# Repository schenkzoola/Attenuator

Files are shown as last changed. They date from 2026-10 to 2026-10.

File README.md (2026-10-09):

<picture>
  <source media="(prefers-color-scheme: dark)" srcset="docs/images/logo-light.png">
  Schenktronics
</picture>

# Levels

A 3HP Eurorack dual passive attenuator from **Schenktronics**. It has two channels, each with an input, an output and a level knob. The second input is normalled to the first, so one signal can be sent out at two different levels. It needs no power.

Levels front panel

## Features

- 3HP Eurorack, 15 mm deep, and it needs no power
- Two channels, each turning a signal down from full level to off
- In 2 is normalled to In 1: one input, two outputs at independent levels
- Works on audio, CV, gates and bipolar signals
- The whole kit is through-hole, with 22 solder joints

## Documentation

| Document | For | PDF |
|---|-----|-----|
| [User Manual](docs/manual.md) | Using the module | [PDF](docs/pdf/levels-manual.pdf) |
| [Assembly Guide](docs/assembly-guide.md) | Building the kit | [PDF](docs/pdf/levels-assembly-guide.pdf) |
| [Bill of Materials](docs/BOM.md) ([CSV](docs/BOM.csv)) | Parts and sourcing | |

## Repository layout

```
hardware/
  levels/                      Main PCB (KiCad 5.1 schematic, KiCad 10 PCB)
    Levels.sch                   Schematic
    Levels.kicad_pcb             PCB layout
    Levels.step                  3D model
    BOM.ods                      Original BOM spreadsheet
  panel/                       Faceplate (KiCad 10, made as an aluminium PCB)
    LevelsFaceplate.kicad_pcb    Faceplate layout
manufacturing/
  levels/                      Gerbers and drill files for the main PCB
  panel/                       Gerbers, drill files and the panel drawing (.dxf)
docs/                         Manual, assembly guide, BOM, images
  drawings/                     Scripts that generate the drawings
  pdf/                          PDF versions and their build settings
```

## Fabrication

| Board | Size | Layers | Thickness | Notes |
|---|---|---|---|---|
| Main PCB | 15 × 100 mm | 2 | 1.6 mm | Standard green is fine |
| Faceplate | 15 × 128.5 mm | 1 | 1.6 mm | Aluminium PCB, white solder mask, black silkscreen. Only the front copper layer is used, so FR4 works too. |

Upload the matching `*Gerbers.zip` to any common PCB fab.

## License

This hardware design and its documentation are licensed under [CC BY-NC-SA 4.0](https://creativecommons.org/licenses/by-nc-sa/4.0/). See [LICENSE](LICENSE).

The Schenktronics name and logo are trademarks of Nathan Schenk and are not covered by the CC BY-NC-SA 4.0 license.

## Links

- Tindie: <https://www.tindie.com/products/schenktronics/passive-attenuator/>
- ModularGrid: <https://modulargrid.net/e/schenktronics-atten>
- Build video: <https://www.youtube.com/watch?v=RKkGsIigaSM>
- Website: <https://schenktronics.com>

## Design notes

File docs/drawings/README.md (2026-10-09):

# Drawings

The drawings in the docs are generated by three scripts in this repo, plus one that lives elsewhere (see "Outline drawings" below). The three here use only the Python standard library.

| Script | Makes | From |
|---|---|---|
| [`make_panel_svg.py`](make_panel_svg.py) | `panel.svg`, used in the manual, and `panel-plain.svg`, the panel without captions, used on packaging labels | The faceplate KiCad file |
| [`make_assembly_svgs.py`](make_assembly_svgs.py) | `assembly-*.svg`, used in the assembly guide | The main PCB KiCad file |
| [`make_patch_svgs.py`](make_patch_svgs.py) | `patch-*.svg`, the patch examples in the manual | The faceplate KiCad file |

## Panel drawing

The panel drawing in the [user manual](../manual.md) ([`../images/panel.svg`](../images/panel.svg)) is generated from the KiCad faceplate file, [`LevelsFaceplate.kicad_pcb`](../../hardware/panel/LevelsFaceplate.kicad_pcb).

After changing the faceplate in KiCad, run this from anywhere in the repo:

```sh
python3 docs/drawings/make_panel_svg.py
```

### What it reads

| From the KiCad file | Used for |
|---|---|
| `Edge.Cuts` lines | Panel outline |
| Mounting-hole footprints and their drill sizes | Jacks (Ø6.0), the knobs (Ø7.0) and the rack screw holes |
| `F.SilkS` lines and text | The divider line and the labels |
| `F.SilkS` circles | The rings around the jacks: a thin ring marks an input, a bold ring an output |
| The `SchentronicsLogo` footprint | The logo, read as its silkscreen polygons and placed at the footprint's position and rotation |

The script tells holes apart by drill size, so if you change a hole size, update `JACK` and `POT` at the top of the script. The knobs are drawn by the script, and the "Level", "In" and "Out" captions are added by the script, not read from KiCad.

The faceplate file is KiCad 10's S-expression format, read with a small generic S-expression parser in the script (not regexes), since the logo's artwork lives inside a footprint and needs that footprint's position and rotation applied to come out right.

## Assembly drawings

After changing the main PCB in KiCad, run:

```sh
python3 docs/drawings/make_assembly_svgs.py
```

| Drawing | How it's made |
|---|---|
| `assembly-1-parts.svg` | Front board view, drawn from the board outline, pads and front silkscreen in the PCB file |
| `assembly-2-faceplate.svg` | Side diagram. The part positions along the board come from the PCB file, and the heights are approximate. |
| `assembly-3-solder.svg` | Back board view, drawn from the PCB file |

Like the panel script, it reads `Levels.kicad_pcb` with the same generic S-expression parser (imported from `make_panel_svg.py`), not regexes — the main PCB file is KiCad 10 format too. It only keeps footprints whose reference starts with `RV` or `J`, so non-component footprints (e.g. the Schenktronics logo artwork on the back silkscreen) don't get drawn as if they were parts.

The side view assumes the faceplate sits 12.5 mm further up than the PCB, matching the two KiCad files. If you move the parts on either board, update `OFFSET` near the top of the figures section.

## Patch examples

The patch drawings reuse the panel drawing and add module boxes and cables. Each example is a short function in the script, for example:

```python
def tame(data):
    p = Patch(data)
    p.source("In 1", "LFO", "out")
    p.dest("Out 1", "Filter", "cutoff CV in")
    p.note("Level 1", "Level 1", "sets the depth")
    ...
```

Jacks are named as on the panel: `In 1`, `Out 1`, `In 2` and `Out 2`. Sources go on the left, destinations on the right. `note()` puts a caption beside a knob or jack. Pass `color=BLUE` to draw a second signal. To add an example, write a new function, add it to the list in `main()`, and run:

```sh
python3 docs/drawings/make_patch_svgs.py
```

## Outline drawings

`outline-front.svg`, `outline-side.svg`, one `outline-iso-{top,bottom}-{left,right}.svg` per corner, and `outline-bare-parts.svg` (the panel and bare PCB side by side, for the assembly guide's "before you start" shot) are real projections straight from [`ST-02_Levels.step`](../../hardware/ST-02_Levels.step) in `hardware/` — not diagrams. They replace the old product photos in the README, manual and assembly guide. All four isometric corners are generated every run so there's always a fresh set to pick a hero shot from; `outline-iso-top-left.svg` is the one currently used.

**The generator for these doesn't live in this repo.** Unlike the three scripts above, it needs no product-specific logic — point it at any product's STEP files and it works unchanged — so it's kept as one shared tool in the private `schenktronics-business` repo (`claude/skills/schenktronics-product-docs/assets/drawings/make_outline_svg.py`) rather than forked into every product. Regenerate from this repo's root:

```sh
pip install cadquery  # no FreeCAD or other CAD tooling needed
python3 ~/Products/schenktronics-business/claude/skills/schenktronics-product-docs/assets/drawings/make_outline_svg.py \
  --assembly hardware/ST-02_Levels.step \
  --panel hardware/panel/LevelsFaceplate.step \
  --board hardware/levels/Levels.step \
  --out docs/images \
  --product "Levels"
```

(or add a view name at the end, e.g. `... outline-front.svg`, to regenerate just that one)

**This is slow, and not predictably so — read the module docstring in that script before touching it.** Short version: a straight-on view down an axis where many cylindrical parts line up end-on (every jack here, viewed from the front) is a degenerate case for exact-BRep HLR, both slow and prone to rendering a different jack inconsistently on every attempt. The fix that worked — a perspective projection with its apex centered on the model, not tilting the orthographic direction — is explained in full in the script itself. That script is the one copy serving every product, so fixes and lessons belong there, not duplicated into each product repo's own docs. One Levels-specific lesson that *did* belong in the shared script: `outline-bare-parts.svg` initially failed here (`Bnd_Box is void`) because a pot's body overhangs the bare board's edge, which the script's board-matching tolerance was too tight to handle — fixed 2026-10-08 by widening that tolerance (see `find_board_solids` in the script).

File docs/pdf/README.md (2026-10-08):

# PDFs

Printable versions of the docs:

- [User Manual (PDF)](levels-manual.pdf)
- [Assembly Guide (PDF)](levels-assembly-guide.pdf)

These are built from [`../manual.md`](../manual.md) and [`../assembly-guide.md`](../assembly-guide.md). **Don't edit the PDFs by hand.** Edit the Markdown instead.

The build tool lives in [schenktronics-docs-tools](https://github.com/schenkzoola/schenktronics-docs-tools), so this repo only holds its settings, in [`config.json`](config.json): the product name, PCB version and which documents to build.

## Automatic builds

The [Build PDFs workflow](../../.github/workflows/pdf.yml) rebuilds the PDFs whenever the docs, their images or `config.json` change on `master`, and commits the new PDFs back. After you push a docs change, wait a minute and then `git pull` to get the rebuilt PDFs.

After an update to schenktronics-docs-tools, run the workflow by hand from the repo's **Actions** tab to rebuild with the new version.

## Previewing locally

See [Previewing locally](https://github.com/schenkzoola/schenktronics-docs-tools#previewing-locally) in the tools repo. In short:

```sh
node ~/Products/schenktronics-docs-tools/pdf/build.mjs docs/pdf/config.json
```

Don't commit the PDFs this produces. Let the workflow build the committed copies.

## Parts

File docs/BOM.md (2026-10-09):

# Bill of Materials — Levels v1.0

A machine-readable copy is in [BOM.csv](BOM.csv). The original spreadsheet is [hardware/levels/BOM.ods](../hardware/levels/BOM.ods).

| Qty | Reference | Part | Manufacturer / Part No. | Notes |
|----:|---|---|---|---|
| 4 | J1–J4 | 3.5 mm mono switched jack, vertical PCB mount, with nut | QingPu WQP-PJ398SM or WQP518MA, or equivalent. Either one works. | [Datasheet / product page](http://www.qingpu-electronics.com/en/products/WQP-PJ398SM-362.html). The switched (normalling) contact is used on J3 (In 2) only, so J3 must be a switched jack. |
| 2 | RV1, RV2 | Potentiometer, 100 kΩ linear, 9 mm, vertical PCB mount with board-lock lugs, 6 mm D shaft (20 mm long), bushingless | Bourns PTV09A-4020F-B104, or equivalent | [Mouser product page](https://www.mouser.com/en/ProductDetail/Bourns/PTV09A-4020F-B104?qs=Qzws7J6gxqwTQanrz88HwA%3D%3D), [datasheet (PTV09 series)](https://www.bourns.com/docs/Product-Datasheets/PTV09.pdf). No center detent. No threaded bushing or nut — held by the PCB's two mounting lugs (the same mounting style as the Attenuverter's pot). An equivalent must fit the 9 mm footprint (3 pins in a row, 2 mounting lugs) and have a 6 mm shaft that fits the knob. |
| 2 | — | Knob, 12 mm | Davies Molding 1221-J, or equivalent | [Mouser 5164-1221-J](https://www.mouser.com/en/ProductDetail/Davies-Molding/1221-J?qs=AaRlLUpeMsymqGRd5ndiLA%3D%3D). Pushes directly onto the pot's shaft — the pot has no nut, so this knob has no skirt (unlike the earlier 1227-J). An equivalent must fit the pot shaft. |
| 1 | — | Main PCB, 15 × 100 mm, 2-layer, 1.6 mm FR4 | Schenktronics | Gerbers: [LevelsGerbers.zip](../manufacturing/levels/LevelsGerbers.zip) |
| 1 | — | Faceplate, 3HP (15 × 128.5 mm), 1.6 mm aluminium PCB | Schenktronics | Single-sided, so it can also be made in FR4. Gerbers: [LevelsFaceplateGerbers.zip](../manufacturing/panel/LevelsFaceplateGerbers.zip) |

## Not included

| Qty | Part | Notes |
|----:|---|---|
| 2 | M3 rack screws | Supplied with most Eurorack cases. |

No power cable is needed. The module is passive.

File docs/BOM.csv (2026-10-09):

Qty | Reference | Description | Manufacturer | Part Number | Link
4 | J1-J4 | 3.5mm mono switched jack, vertical, with nut (J3 must be switched) | QingPu | WQP-PJ398SM or WQP518MA | http://www.qingpu-electronics.com/en/products/WQP-PJ398SM-362.html
2 | RV1, RV2 | Potentiometer, 100k linear, 9mm, vertical PCB mount with board-lock lugs, 6mm D shaft (20mm long), bushingless, no nut (or equivalent) | Bourns | PTV09A-4020F-B104 | https://www.mouser.com/en/ProductDetail/Bourns/PTV09A-4020F-B104
2 |  | Knob, 12mm, fits pot shaft directly, not skirted (or equivalent) | Davies Molding | 1221-J | https://www.mouser.com/en/ProductDetail/Davies-Molding/1221-J
1 |  | Main PCB, 15x100mm, 2-layer, 1.6mm | Schenktronics | Levels v1.0
1 |  | Faceplate, 3HP, 1.6mm aluminium PCB | Schenktronics | Levels Faceplate

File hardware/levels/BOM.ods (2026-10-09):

Qty | Part No | Manufacturer | Description | Link
4 | WQP-WQP518MA | QuingPu | 3.5mm Jack with nut | http://www.qingpu-electronics.com/en/products/WQP-PJ398SM-362.html
2 | PTV09A-4020F-B104 | Bourns | POT 100K OHM 1/20W PLASTIC LIN | https://www.mouser.com/en/ProductDetail/Bourns/PTV09A-4020F-B104?qs=Qzws7J6gxqwTQanrz88HwA%3D%3D
2 | 1221-J | Davies Molding | 15mm x 22mm skirted knob | https://www.mouser.com/en/ProductDetail/Davies-Molding/1221-J?qs=AaRlLUpeMsymqGRd5ndiLA%3D%3D
1 | PCB | Schenktronics
1 | Faceplate | Schenktronics

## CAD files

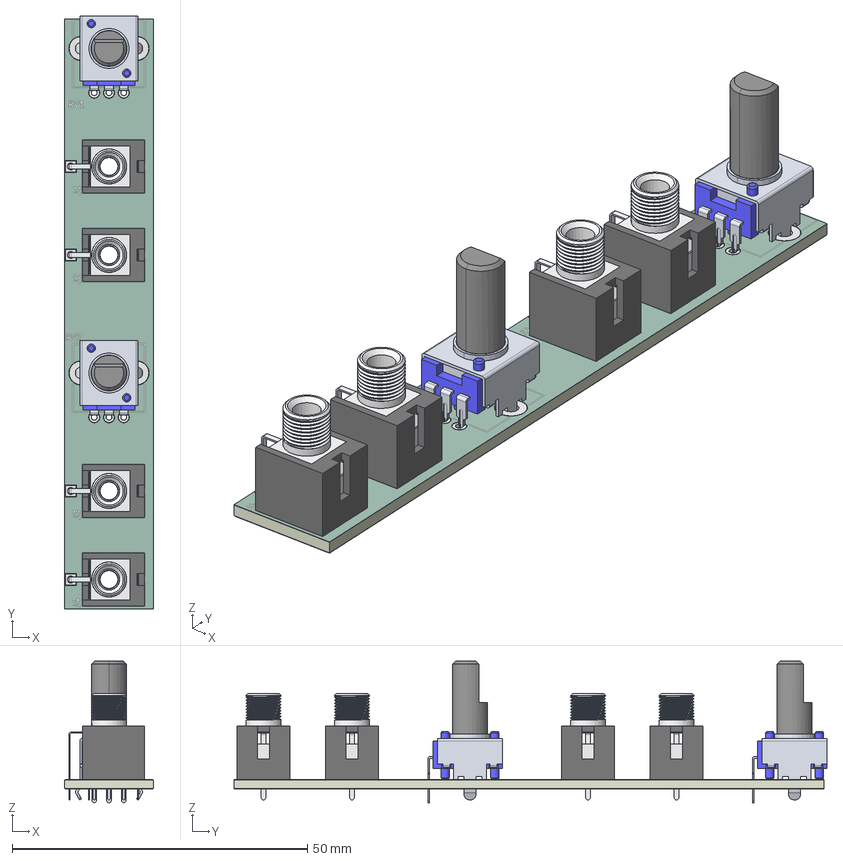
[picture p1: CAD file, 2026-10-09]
hardware/levels/Levels.step
15.0 x 100.5 x 24.0 mm
Thonkiconn - PJ398SM v10 x 4
PTV09A-4X20F-XXXCX_2 x 2
PTV09A-4X20F-XXXCX x 2
Levels_copper
Levels_pad
Levels_silkscreen x 2
Levels_soldermask x 2
Levels_PCB

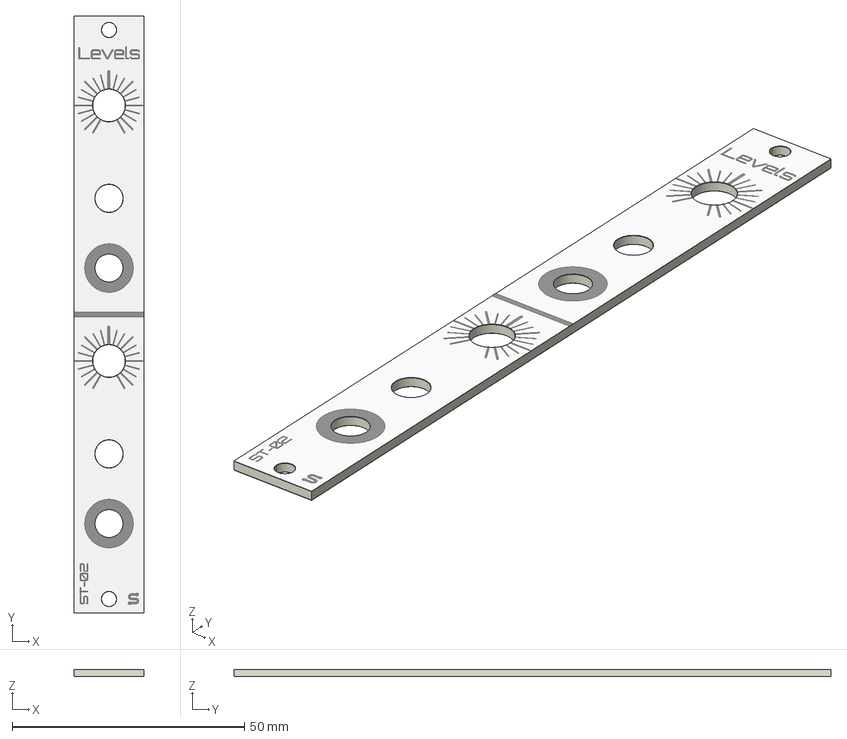
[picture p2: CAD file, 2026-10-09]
hardware/panel/LevelsFaceplate.step
15.0 x 128.5 x 1.64 mm
LevelsFaceplate-unsaved-export-oxjU8a_copper
LevelsFaceplate-unsaved-export-oxjU8a_silkscreen
LevelsFaceplate-unsaved-export-oxjU8a_soldermask x 2
LevelsFaceplate-unsaved-export-oxjU8a_PCB

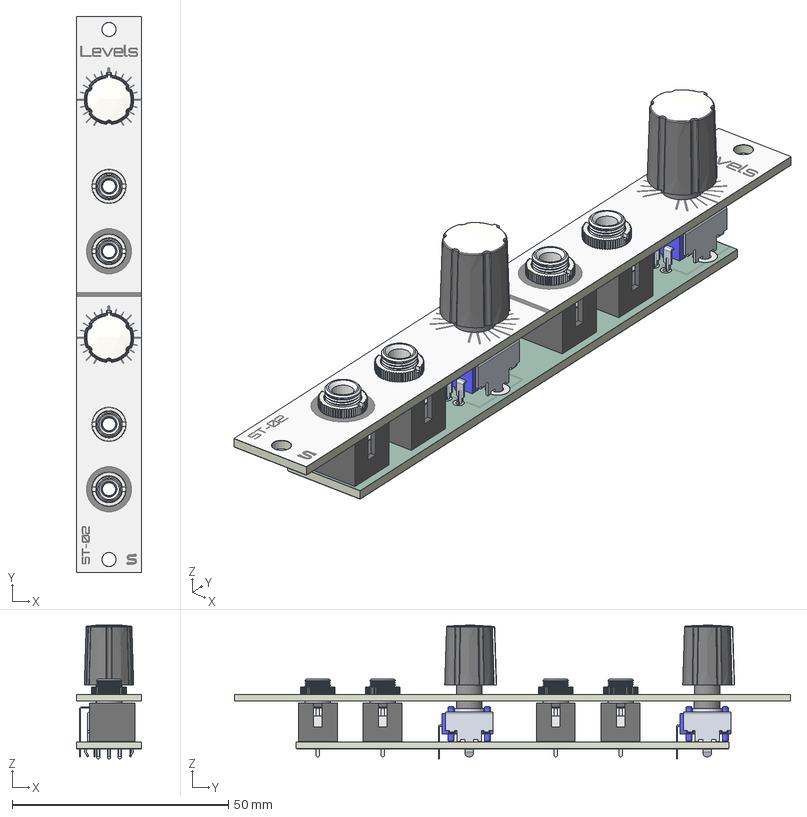
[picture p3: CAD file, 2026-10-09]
hardware/ST-02_Levels.step
15.0 x 128.5 x 31.0 mm
Thonkiconn - PJ398SM v10 x 4
PTV09A-4X20F-XXXCX_2 x 2
PTV09A-4X20F-XXXCX x 2
Levels_copper
Levels_pad
Levels_silkscreen
Levels_silkscreen_1
Levels_soldermask
Levels_soldermask_1
Levels_PCB
LevelsFaceplate-unsaved-export-oxjU8a_copper
LevelsFaceplate-unsaved-export-oxjU8a_silkscreen
LevelsFaceplate-unsaved-export-oxjU8a_soldermask
LevelsFaceplate-unsaved-export-oxjU8a_soldermask_1
LevelsFaceplate-unsaved-export-oxjU8a_PCB
Davies 1221-J x 2

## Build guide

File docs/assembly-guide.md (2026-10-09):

# Levels — Assembly Guide

Building this kit takes about 20–30 minutes and needs 22 solder joints. It is a good first Eurorack kit.

**Prefer to watch?** There's a video of the whole build: [Watch me solder together a passive attenuator module!](https://www.youtube.com/watch?v=RKkGsIigaSM)

The faceplate and the bare PCB, before assembly

## What you need

### Kit contents

Check your kit against this list before you start (full details in the [BOM](BOM.md)):

- [ ] 1 × main PCB
- [ ] 1 × faceplate
- [ ] 4 × 3.5 mm jacks with nuts
- [ ] 2 × 100 kΩ linear potentiometers
- [ ] 2 × knobs

### Tools

- Soldering iron (about 330–360 °C for leaded solder)
- Solder
- Flush cutters
- Multimeter with continuity (beep) and resistance modes
- Nut driver or wrench for the jack nuts (optional, but it avoids scratching the panel)

## Before you start

- The pots and jacks go on the **front** of the PCB, which is the side with the part outlines (RV1, RV2, J1–J4). The side printed "ST-02 v1.0 / Levels / schenktronics.com" is the back, and you solder there.
- **Do not solder anything until the faceplate is fitted.** The pot shafts and jacks all pass through the faceplate, which holds them in line while you solder. Parts soldered first can end up crooked in their panel holes.

## Step 1 — Fit the pots and jacks

1. Push the two pots into RV1 and RV2 from the front of the PCB. Each pot fits only one way round: the three pins go in the row of three small holes and the two mounting lugs go in the large holes. The lugs clip into the board and hold the pot in place.
2. Insert the four jacks into J1–J4 from the front of the PCB. Make sure each jack sits flat, with all three legs through their pads.
3. Don't solder anything yet.

Front of the PCB with the positions of RV1, RV2 and J1 to J4 highlighted

## Step 2 — Fit the faceplate

1. Remove the nuts (and any washers) from the jacks. The pots have no nuts.
2. Lower the faceplate over the parts. The "Atten." label goes at the top, over RV1. The pot shafts go through the two larger holes.
3. Put the jack nuts back on and tighten them **finger-tight** for now.
4. Check that each pot shaft is centered in its hole, and that the PCB is parallel to the faceplate. The shafts are thinner than their holes, and nothing but the solder will hold them, so centering them now stops the knobs rubbing later. The legs have a little play in their holes, which gives you room to adjust.
5. Tighten the jack nuts snugly. Do not overtighten them, because that can crack the jack threads or mark the panel.

Exploded side view: pots and jacks on the PCB, the faceplate above them, and the jack nuts on top

## Step 3 — Solder the pots and jacks

Turn the assembly over and solder from the back of the PCB.

1. Tack one leg of each part: the square pad of each jack and the middle pin of each pot. Then check again that the pot shafts are still centered. If one isn't, reheat that joint and adjust.
2. Solder the remaining pins and pads.
3. Solder the four large mounting-lug pads of the pots. They connect to the ground plane, so they take a little longer to heat. Hold the iron on until the solder flows into the hole.
4. Trim any long leads with flush cutters.

Back of the PCB: one pad per part to tack first is filled red, and the other pads, including the pot lugs, are outlined in red

Inspect every joint. Each one should be shiny and cone-shaped, with no bridges between neighboring pads.

## Step 4 — Fit the knobs

Push each knob onto its pot shaft. The flat on the shaft sets the knob's position, so there's nothing to align. Check that each knob turns without rubbing on the panel.

## Step 5 — Test

Test with a multimeter. No power is needed. The easiest way to reach the tip and sleeve of a jack is to plug in a patch cable and probe its plug. "Beep" means continuity mode; "Ω" means resistance mode.

| Test | Expected result |
|---|---|
| Sleeve of any jack ↔ sleeve of every other jack | Beep |
| In 1 tip ↔ Out 1 tip, Level 1 fully clockwise | Beep, or a few ohms |
| Out 1 tip ↔ sleeve, Level 1 fully anticlockwise | Beep, or a few ohms |
| In 2 tip ↔ Out 2 tip, Level 2 fully clockwise | Beep, or a few ohms |
| Out 2 tip ↔ sleeve, Level 2 fully anticlockwise | Beep, or a few ohms |
| Cable in In 1 only: In 1 tip ↔ Out 2 tip, Level 2 fully clockwise | Beep (the normal is working) |
| Same, with a second cable plugged into In 2 | **No beep** (the normal is broken) |
| In 1 tip ↔ sleeve, nothing in In 2 (Ω) | About 50 kΩ (both pots in parallel). **Near 0 Ω means a short.** Check for solder bridges. |
| In 2 tip ↔ sleeve, cable in In 2 (Ω) | About 100 kΩ. **Near 0 Ω means a short.** |

## Step 6 — Install

Install the module in your case with two M3 screws. Usage details are in the [User Manual](manual.md).

Assembled module, isometric view

## Troubleshooting

| Symptom | Likely cause |
|---|---|
| One jack is dead | That jack has a cold or missing solder joint. Reflow its legs. |
| Out 2 is silent with a cable in In 1 and nothing in In 2 | The normalling contact on J3 (In 2) isn't soldered well. Reflow all three J3 legs. |
| A knob does nothing, or the output jumps | A bad joint on that pot. Reflow its three pins. |
| The signal is shorted to ground | There is a solder bridge between a tip pad and a ground pad or lug. |
| A knob rubs on the panel | The knob is pushed on too far. Pull it out slightly. |
| A pot shaft is crooked in its hole | It wasn't centered before soldering. Reheat the pot's pins and lugs, and straighten it. |
| Full level is a little quieter than the input | This is normal for a passive attenuator. See [Good practice](manual.md#good-practice) in the manual. |

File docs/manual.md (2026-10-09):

# Levels — User Manual

Levels front panel

## Overview

Levels is a 3HP Eurorack utility module with two attenuators. Each one takes a signal at its input and gives you a quieter or smaller copy at its output, set by its knob. In 2 is normalled to In 1, so a single signal can feed both channels at different levels.

The module is just jacks and potentiometers, so it does not need power.

## Specifications

| | |
|---|---|
| Format | Eurorack, 3HP |
| Panel | 15 × 128.5 mm |
| Depth | 15 mm (skiff-friendly) |
| Power | None needed |
| Jacks | 4 × 3.5 mm mono (TS): 2 inputs, 2 outputs |
| Controls | 2 × level knobs, 100 kΩ linear potentiometers |
| Range | Off (fully anticlockwise) to full level (fully clockwise). It can't amplify or invert. |
| Signals | Audio, CV, gates, and both unipolar and bipolar signals |

Side view of the assembled module, showing the panel, PCB, jacks and pots

## Panel layout

Panel layout: channel 1 on top (Level 1, In 1, Out 1), a divider line, then channel 2 (Level 2, In 2, Out 2)

The panel has two identical channels, separated by the thick line. In each channel, the knob is at the top; below it, the nearer jack is the **input** (unmarked), and the farther jack is the **output**, marked with a **bold ring**.

## Using the module

### Level knobs

Turn a knob clockwise for more signal. Fully anticlockwise, the output is at 0 V (off). Fully clockwise, the output is close to the full input signal. It is never louder than the input, because the module has no amplifier.

The knob scales the signal toward 0 V. A bipolar LFO swinging ±5 V becomes a smaller swing around 0 V. It isn't shifted or offset.

### Normalled input

In 2 is normalled to In 1. When nothing is plugged into In 2, channel 2 gets its signal from In 1. Plug a cable into In 2 to break the normal and use the channels separately.

So with one cable into In 1:

- **Out 1** gives the signal at the Level 1 setting.
- **Out 2** gives the same signal at the Level 2 setting.

This is a quick way to send one modulation source to two places at different depths.

### Using it on audio

An attenuator on an audio signal is a volume control. Use it to bring a hot oscillator down before a filter or effect, or to set a manual mix level before a mixer that has no level controls.

## Patch examples

Each drawing shows the module that sends the signal on the left and the modules that receive it on the right.

### Set the depth of an LFO

An LFO patched into In 1, with Out 1 going to a filter's cutoff CV input

Many filter CV inputs have no attenuator, so a full-size LFO sweeps the filter from closed to wide open. Patch the LFO through channel 1 and use Level 1 to set how far it sweeps.

### One LFO at two depths

An LFO patched into In 1, with Out 1 to a filter's cutoff and Out 2 to a VCO's pulse width input; In 2 is empty

Leave In 2 empty and the LFO reaches both channels. Here Level 1 sets how much the filter moves and Level 2 sets how much the pulse width moves, from one cable.

### Two separate attenuators

An envelope through channel 1 into a VCA, and a VCO's audio through channel 2 into a mixer

With a cable in In 2, the channels are independent. Here channel 1 sets how far an envelope opens a VCA, and channel 2 turns a VCO down before a mixer.

## Good practice

- **Patch outputs into the inputs.** Plug sources into the In jacks (unmarked), not the Out jacks (bold ring). A source patched into an Out jack is wired straight to the knob's wiper, so the knob won't work as expected, and turning it fully anticlockwise connects that source directly to ground. Most Eurorack outputs are protected against this, but not all are, so avoid it.
- **Full level is slightly below the input.** A passive attenuator loads the module feeding it and the module it feeds. With typical Eurorack modules, fully clockwise gives a little less than the original signal, and the middle of the knob gives a bit less than half. This is normal for any passive attenuator. For exact levels, use a buffered attenuator.
- **Pitch CV (V/oct):** attenuating a pitch CV changes the intervals, so the oscillator won't track in tune. That can be a creative effect, but it's not a way to transpose.
- **One source into both channels:** when In 2 is empty, In 1 feeds both knobs, so it loads the source a little more. It makes no difference with most modules.
- **Grounds:** the sleeves of all four jacks are wired together.

## Installation

1. Power off your case. The module does not need power, but you should never work in a powered case.
2. Place the module in any 3HP space. There is no ribbon cable to connect.
3. Secure it with two M3 rack screws. Do not overtighten them.

## Circuit

Each channel is one potentiometer wired as a voltage divider. The input jack's tip goes to one end of the pot, the other end goes to ground, and the wiper goes to the output jack's tip. In 2 (J3) is a switched jack: its normalling contact is wired to the tip of In 1 (J1), so In 1 feeds channel 2 until a plug is inserted in In 2. All sleeves and the pots' mounting lugs are wired to ground. The schematic is in [hardware/levels/Levels.sch](../hardware/levels/Levels.sch) (KiCad 5).

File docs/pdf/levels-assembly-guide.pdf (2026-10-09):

Building this kit takes about 20–30 minutes and needs 22 solder joints. It is a good first Eurorack kit.

Prefer to watch? There's a video of the whole build: Watch me solder together a passive attenuator module! (ht

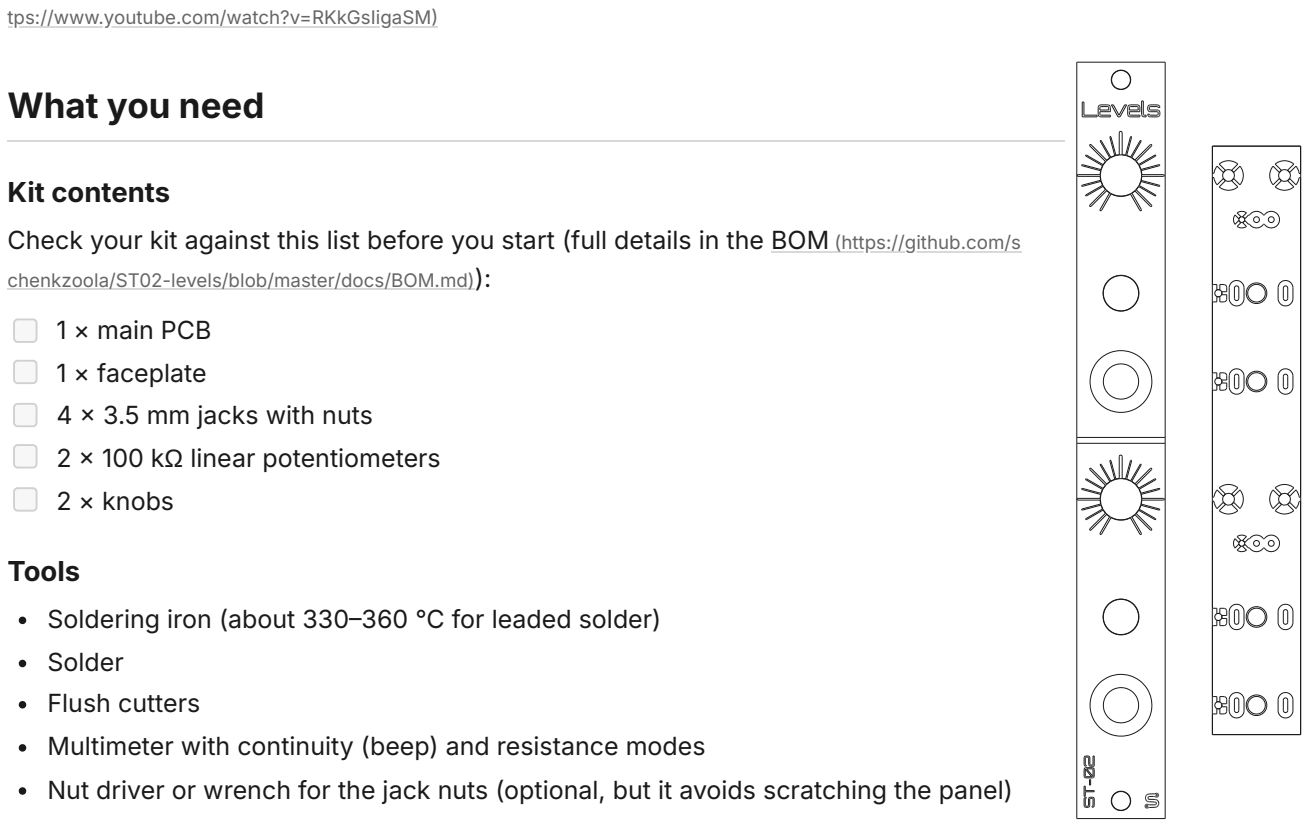
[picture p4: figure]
tps://www.youtube.com/watch?v=RKkGsIigaSM); What you need; Kit contents; chenkzoola/ST02-levels/blob/master/docs/BOM.md)):; 1 × main PCB 1 × faceplate 4 × 3.5 mm jacks with nuts 2 × 100 kΩ linear potentiometers 2 × knobs; Tools; Solder Flush cutters

Check your kit against this list before you start (full details in the BOM (https://github.com/s

Soldering iron (about 330–360 °C for leaded solder)

Multimeter with continuity (beep) and resistance modes
Nut driver or wrench for the jack nuts (optional, but it avoids scratching the panel)

## Before you start

The pots and jacks go on the front of the PCB, which is the side with the part outlines (RV1, RV2, J1–J4). The side printed "ST-02 v1.0 / Levels / schenktronics.com" is the back, and you solder there.
Do not solder anything until the faceplate is fitted. The pot shafts and jacks all pass through the faceplate, which holds them in line while you solder. Parts soldered first can end up crooked in their panel holes.

# Levels

## Assembly Guide

For PCB v1.0 · Updated 2026-10-08
Official version: github.com/schenkzoola/ST02-levels
Levels · Assembly Guide · PCB v1.0 | schenktronics.com · CC BY-NC-SA 4.0 | Page 1 of 4

## Step 1 — Fit the pots and jacks

1. Push the two pots into RV1 and RV2 from the front of the PCB. Each pot fits only one way round: the three pins go in the row of three small holes and the two mounting lugs go in the large holes. The lugs clip into the board and hold the pot in place.
2. Insert the four jacks into J1–J4 from the front of the PCB. Make sure each jack sits flat, with all three legs through their pads.
3. Don't solder anything yet.

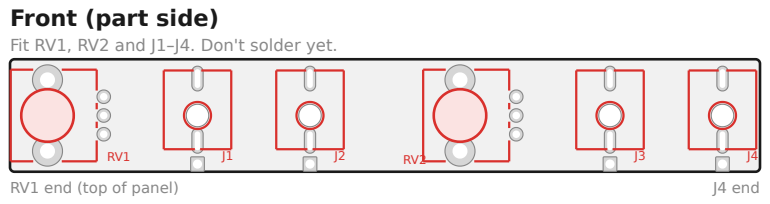
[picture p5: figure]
Front (part side); RV1 end (top of panel); J4 end

Fit RV1, RV2 and J1–J4. Don't solder yet.

## Step 2 — Fit the faceplate

1. Remove the nuts (and any washers) from the jacks. The pots have no nuts.
2. Lower the faceplate over the parts. The "Atten." label goes at the top, over RV1. The pot shafts go through the two larger holes.
3. Put the jack nuts back on and tighten them finger-tight for now.
4. Check that each pot shaft is centered in its hole, and that the PCB is parallel to the faceplate. The shafts are thinner than their holes, and nothing but the solder will hold them, so centering them now stops the knobs rubbing later. The legs have a little play in their holes, which gives you room to adjust.
5. Tighten the jack nuts snugly. Do not overtighten them, because that can crack the jack threads or mark the

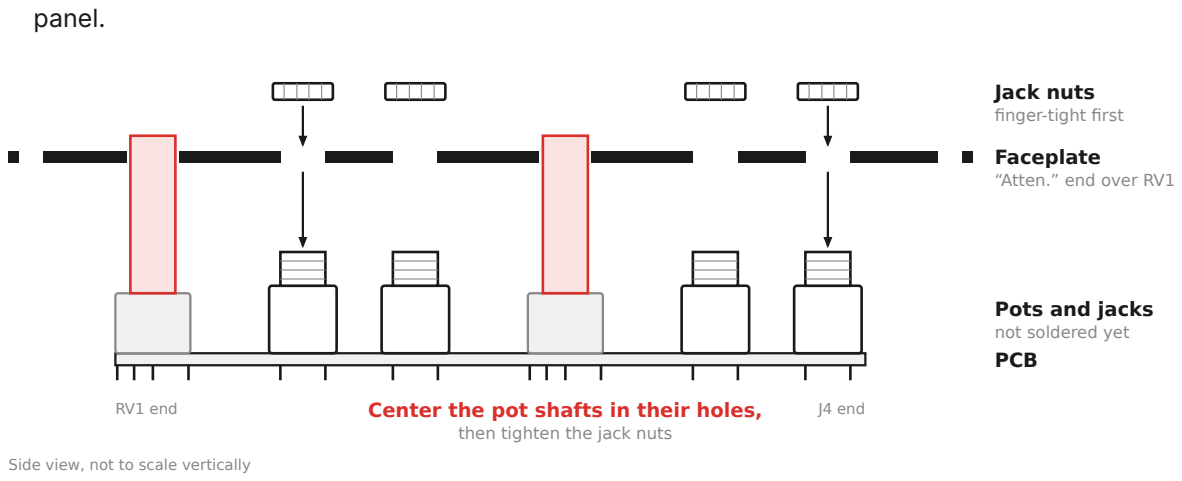
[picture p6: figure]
panel.; Jack nuts finger-tight first; Faceplate “Atten.” end over RV1; Pots and jacks not soldered yet PCB; Center the pot shafts in their holes, then tighten the jack nuts; RV1 end; J4 end; Side view, not to scale vertically

## Step 3 — Solder the pots and jacks

Turn the assembly over and solder from the back of the PCB.

1. Tack one leg of each part: the square pad of each jack and the middle pin of each pot. Then check again that the pot shafts are still centered. If one isn't, reheat that joint and adjust.
Levels · Assembly Guide · PCB v1.0 | schenktronics.com · CC BY-NC-SA 4.0 | Page 2 of 4

2. Solder the remaining pins and pads.
3. Solder the four large mounting-lug pads of the pots. They connect to the ground plane, so they take a little longer to heat. Hold the iron on until the solder flows into the hole.
4. Trim any long leads with flush cutters.

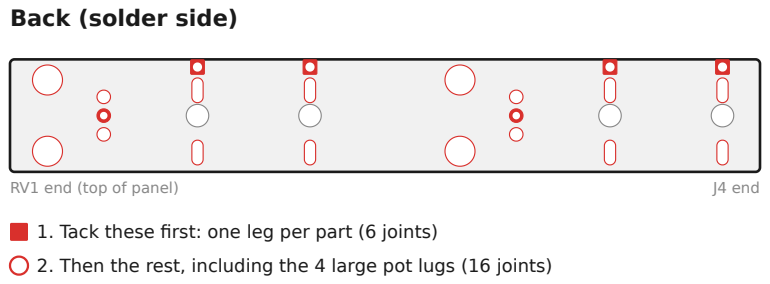
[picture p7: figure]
Back (solder side); RV1 end (top of panel); J4 end

1. Tack these first: one leg per part (6 joints)
2. Then the rest, including the 4 large pot lugs (16 joints)

Inspect every joint. Each one should be shiny and cone-shaped, with no bridges between neighboring pads.

## Step 4 — Fit the knobs

Push each knob onto its pot shaft. The flat on the shaft sets the knob's position, so there's nothing to align. Check that each knob turns without rubbing on the panel.

## Step 5 — Test

Test with a multimeter. No power is needed. The easiest way to reach the tip and sleeve of a jack is to plug in a patch cable and probe its plug. "Beep" means continuity mode; "Ω" means resistance mode.

Test | Expected result
Sleeve of any jack ↔ sleeve of every other jack | Beep
In 1 tip ↔ Out 1 tip, Level 1 fully clockwise | Beep, or a few ohms
Out 1 tip ↔ sleeve, Level 1 fully anticlockwise | Beep, or a few ohms
In 2 tip ↔ Out 2 tip, Level 2 fully clockwise | Beep, or a few ohms
Out 2 tip ↔ sleeve, Level 2 fully anticlockwise | Beep, or a few ohms
Cable in In 1 only: In 1 tip ↔ Out 2 tip, Level 2 fully clockwise | Beep (the normal is working)
Same, with a second cable plugged into In 2 | No beep (the normal is broken)
In 1 tip ↔ sleeve, nothing in In 2 (Ω) | About 50 kΩ (both pots in parallel). Near 0 Ω means a short. Check for solder bridges.
In 2 tip ↔ sleeve, cable in In 2 (Ω) | About 100 kΩ. Near 0 Ω means a short.

## Step 6 — Install

Install the module in your case with two M3 screws. Usage details are in the User Manual (https://github.com/schenk
zoola/ST02-levels/blob/master/docs/manual.md). (https://github.com/schenkzoola/ST02-levels/blob/master/docs/manual.md)
Levels · Assembly Guide · PCB v1.0 | schenktronics.com · CC BY-NC-SA 4.0 | Page 3 of 4

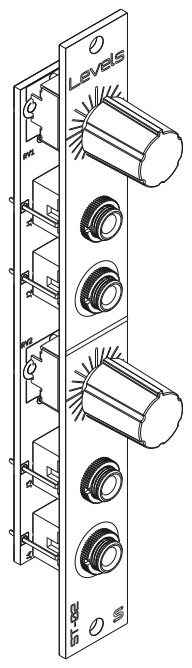
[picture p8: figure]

## Troubleshooting

Symptom | Likely cause
One jack is dead | That jack has a cold or missing solder joint. Reflow its legs.
Out 2 is silent with a cable in In 1 and nothing in In 2 | The normalling contact on J3 (In 2) isn't soldered well. Reflow all three J3 legs.
A knob does nothing, or the output jumps | A bad joint on that pot. Reflow its three pins.
The signal is shorted to ground | There is a solder bridge between a tip pad and a ground pad or lug.
A knob rubs on the panel | The knob is pushed on too far. Pull it out slightly.

A pot shaft is crooked in its hole It wasn't centered before soldering. Reheat the pot's pins and lugs, and straighten it.

Full level is a little quieter than the input | This is normal for a passive attenuator. See Good practice (https://github.com/schenkzool a/ST02-levels/blob/master/docs/manual.md#good-practice) (https://github.com/schenkzoola/ST02-levels/blob/master/docs/manual.md#good-practice) in the manual.
Levels · Assembly Guide · PCB v1.0 | schenktronics.com · CC BY-NC-SA 4.0 | Page 4 of 4

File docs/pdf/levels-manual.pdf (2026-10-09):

## Overview

Levels is a 3HP Eurorack utility module with two attenuators. Each one takes a signal at its input and gives you a quieter or smaller copy at its output, set by its knob. In 2 is normalled to In 1, so a single signal can feed both channels at different levels.

The module is just jacks and potentiometers, so it does not need power.

## Specifications

Format | Eurorack, 3HP
Panel | 15 × 128.5 mm
Depth | 15 mm (skiff-friendly)
Power | None needed
Jacks | 4 × 3.5 mm mono (TS): 2 inputs, 2 outputs

Controls 2 × level knobs, 100 kΩ linear potentiometers

Range | Off (fully anticlockwise) to full level (fully clockwise). It can't amplify or invert.
Signals | Audio, CV, gates, and both unipolar and bipolar signals

# Levels

## User Manual

For PCB v1.0 · Updated 2026-10-08
Official version: github.com/schenkzoola/ST02-levels
Levels · User Manual · PCB v1.0 | schenktronics.com · CC BY-NC-SA 4.0 | Page 1 of 5

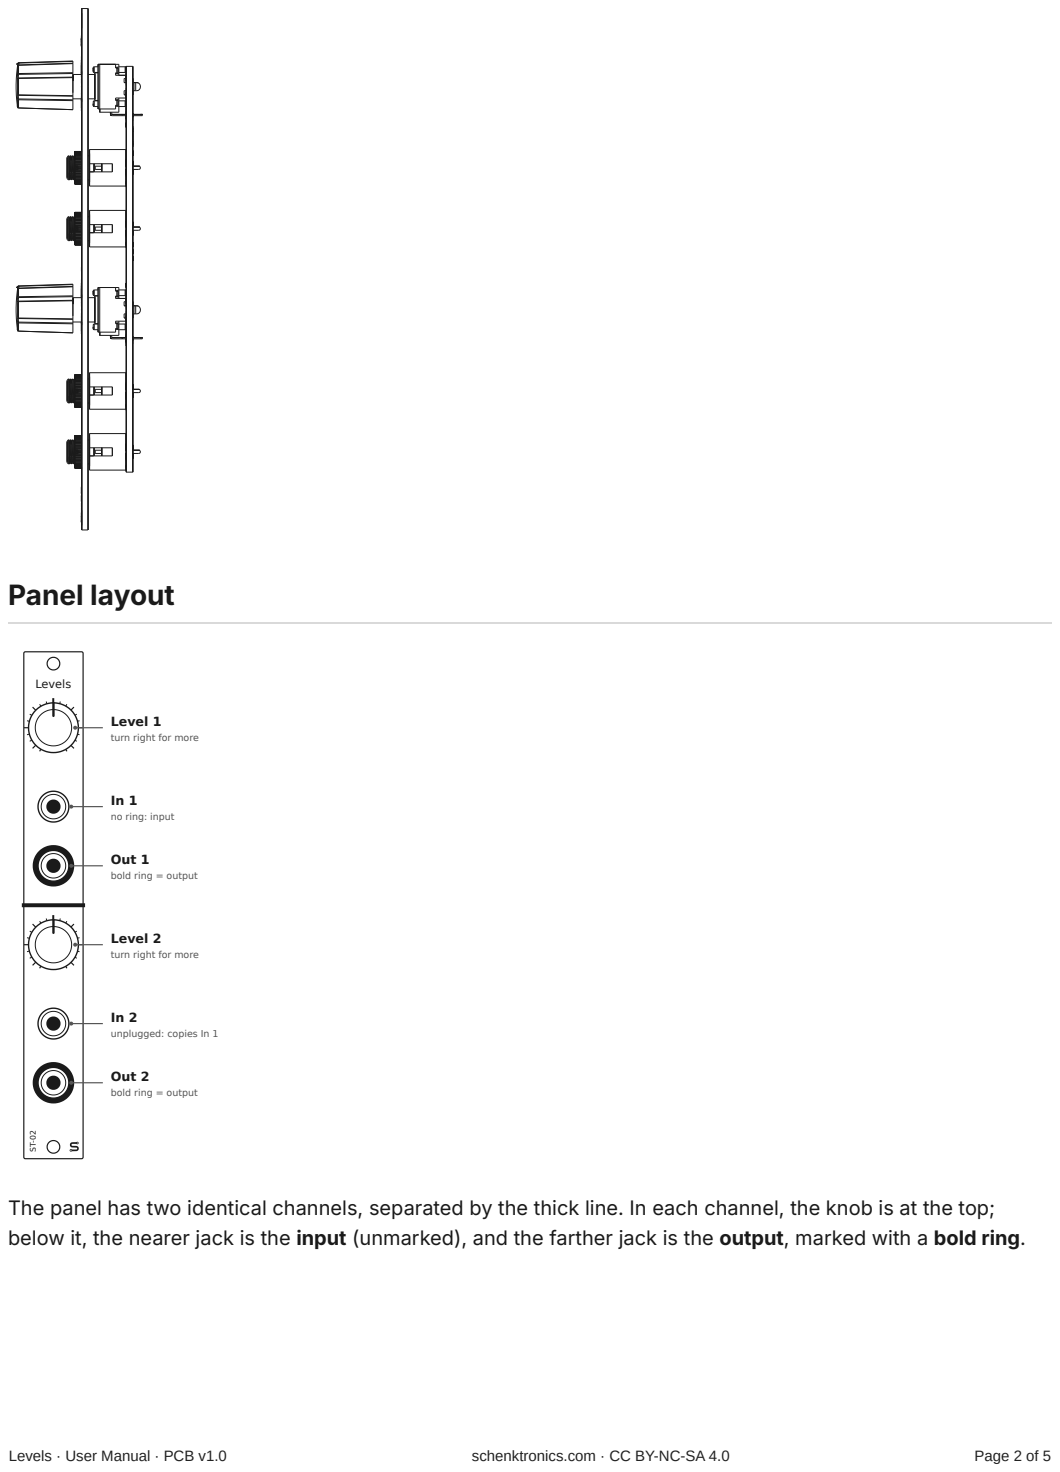
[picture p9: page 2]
Panel layout; ST-02 Levels; Levels · User Manual · PCB v1.0; schenktronics.com · CC BY-NC-SA 4.0; Page 2 of 5

Level 1
turn right for more

no ring: input

Out 1
bold ring = output

Level 2

unplugged: copies In 1

Out 2

The panel has two identical channels, separated by the thick line. In each channel, the knob is at the top;
below it, the nearer jack is the input (unmarked), and the farther jack is the output, marked with a bold ring.

## Using the module

Level knobs
Turn a knob clockwise for more signal. Fully anticlockwise, the output is at 0 V (off). Fully clockwise, the output is close to the full input signal. It is never louder than the input, because the module has no amplifier.

The knob scales the signal toward 0 V. A bipolar LFO swinging ±5 V becomes a smaller swing around 0 V. It isn't shifted or offset.

Normalled input
In 2 is normalled to In 1. When nothing is plugged into In 2, channel 2 gets its signal from In 1. Plug a cable into In 2 to break the normal and use the channels separately.

So with one cable into In 1:

Out 1 gives the signal at the Level 1 setting.
Out 2 gives the same signal at the Level 2 setting.
This is a quick way to send one modulation source to two places at different depths.

Using it on audio
An attenuator on an audio signal is a volume control. Use it to bring a hot oscillator down before a filter or effect, or to set a manual mix level before a mixer that has no level controls.

## Patch examples

Each drawing shows the module that sends the signal on the left and the modules that receive it on the right.

Set the depth of an LFO

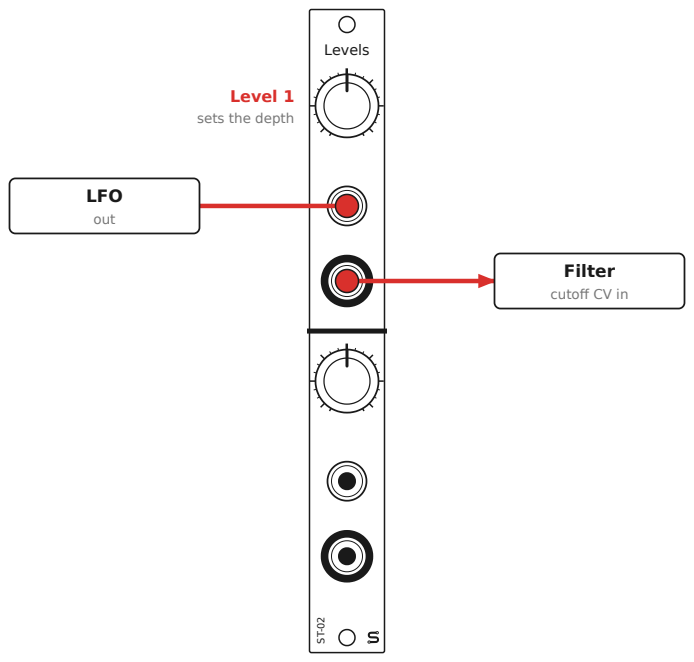
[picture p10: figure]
ST-02 Levels; LFO; out; Filter; cutoff CV in; Level 1 sets the depth

Levels · User Manual · PCB v1.0 | schenktronics.com · CC BY-NC-SA 4.0 | Page 3 of 5

Many filter CV inputs have no attenuator, so a full-size LFO sweeps the filter from closed to wide open. Patch the LFO through channel 1 and use Level 1 to set how far it sweeps.

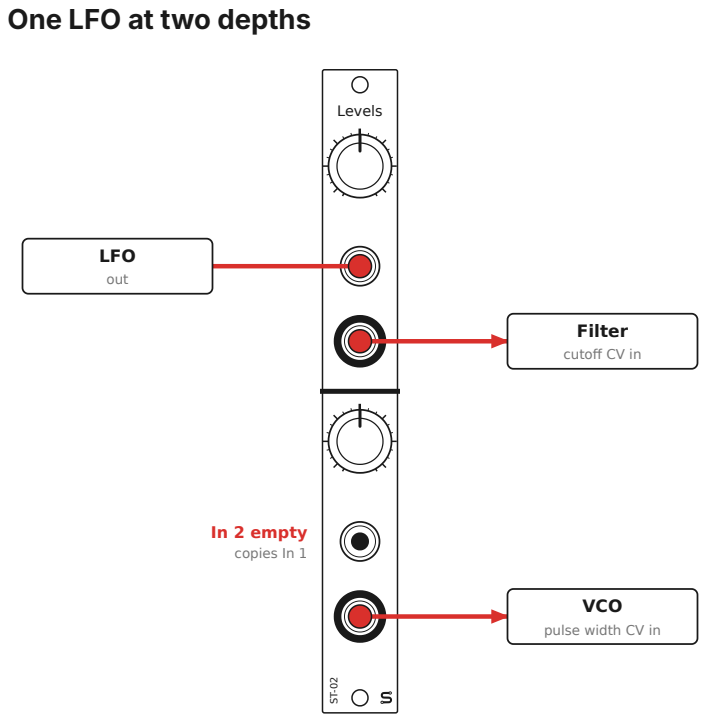
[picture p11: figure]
One LFO at two depths; ST-02 Levels; LFO; out; Filter; cutoff CV in; VCO; pulse width CV in; In 2 empty copies In 1

Leave In 2 empty and the LFO reaches both channels. Here Level 1 sets how much the filter moves and Level 2 sets how much the pulse width moves, from one cable.

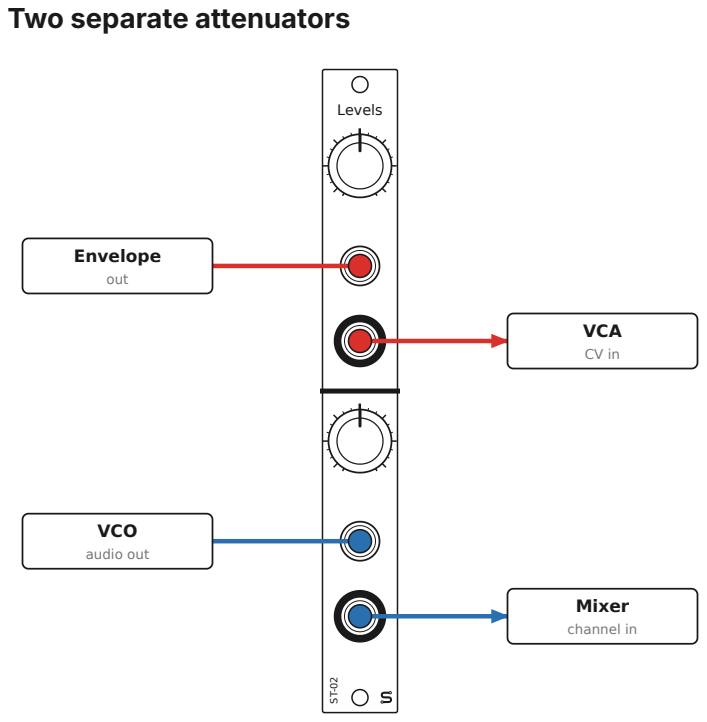
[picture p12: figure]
Two separate attenuators; ST-02 Levels; Envelope; out; VCA; VCO; audio out; Mixer; channel in

Levels · User Manual · PCB v1.0 | schenktronics.com · CC BY-NC-SA 4.0 | Page 4 of 5

With a cable in In 2, the channels are independent. Here channel 1 sets how far an envelope opens a VCA, and channel 2 turns a VCO down before a mixer.

## Good practice

Patch outputs into the inputs. Plug sources into the In jacks (unmarked), not the Out jacks (bold ring). A source patched into an Out jack is wired straight to the knob's wiper, so the knob won't work as expected, and turning it fully anticlockwise connects that source directly to ground. Most Eurorack outputs are protected against this, but not all are, so avoid it.
Full level is slightly below the input. A passive attenuator loads the module feeding it and the module it feeds. With typical Eurorack modules, fully clockwise gives a little less than the original signal, and the middle of the knob gives a bit less than half. This is normal for any passive attenuator. For exact levels, use a buffered attenuator.
Pitch CV (V/oct): attenuating a pitch CV changes the intervals, so the oscillator won't track in tune. That can be a creative effect, but it's not a way to transpose.
One source into both channels: when In 2 is empty, In 1 feeds both knobs, so it loads the source a little more. It makes no difference with most modules.
Grounds: the sleeves of all four jacks are wired together.

## Installation

1. Power off your case. The module does not need power, but you should never work in a powered case.
2. Place the module in any 3HP space. There is no ribbon cable to connect.
3. Secure it with two M3 rack screws. Do not overtighten them.

## Circuit

Each channel is one potentiometer wired as a voltage divider. The input jack's tip goes to one end of the pot, the other end goes to ground, and the wiper goes to the output jack's tip. In 2 (J3) is a switched jack: its normalling contact is wired to the tip of In 1 (J1), so In 1 feeds channel 2 until a plug is inserted in In 2. All sleeves and the pots' mounting lugs are wired to ground. The schematic is in hardware/levels/Levels.sch (http
s://github.com/schenkzoola/ST02-levels/blob/master/hardware/levels/Levels.sch) (KiCad 5).
Levels · User Manual · PCB v1.0 | schenktronics.com · CC BY-NC-SA 4.0 | Page 5 of 5

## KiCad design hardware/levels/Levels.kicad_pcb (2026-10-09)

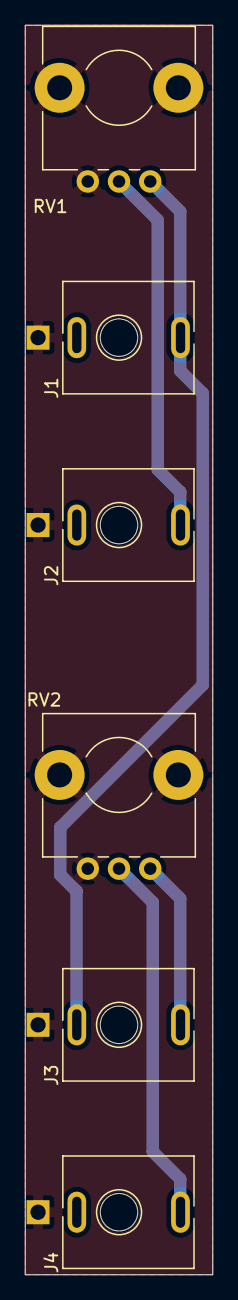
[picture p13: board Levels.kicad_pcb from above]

Board: 2 copper layers, 15.0 x 100.0 mm, 6 parts (0 on the bottom side), 5 nets.

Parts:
J1, J2, J3, J4: AudioJack2_SwitchT; Jack_3.5mm_QingPu_WQP-PJ398SM_Vertical_CenterHole_OvalPads
RV1, RV2: R_POT; Potentiometer_Alps_RK09L_Plated_Mount_Holes

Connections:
GND: J1.S, J2.S, J3.S, J4.S, RV1.3, RV2.3
unnamed: J1.T, J3.TN, RV1.1
unnamed: J2.T, RV1.2
unnamed: J3.T, RV2.1
unnamed: J4.T, RV2.2

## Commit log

2019-11-25 Moved potentiometers to top.
    Add top layer gnd pour
    [PassiveAttenuator.kicad_pcb]
2019-11-25 Add BOM
    [BOM.ods]
2019-11-26 Generate gerbers and step
    [PassiveAttenuator-B_Cu.gbr, PassiveAttenuator-B_Mask.gbr, PassiveAttenuator-B_Paste.gbr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]
2019-11-27 Move jacks to center
    [PassiveAttenuator-B_Cu.gbr, PassiveAttenuator-B_Mask.gbr, PassiveAttenuator-B_Paste.gbr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]
2019-11-27 Add faceplate .dxf
    [PassiveAttenuatorFaceplate.dxf]
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2019-11-28 Finish faceplate, add gerbers
    [PassiveAttenuatorFaceplate-B_Cu.gbr, PassiveAttenuatorFaceplate-B_Mask.gbr, PassiveAttenuatorFaceplate-B_Paste.gbr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]
2019-12-04 Update lower two jack holes in faceplate.
    [PassiveAttenuatorFaceplate-B_Cu.gbr, PassiveAttenuatorFaceplate-B_Mask.gbr, PassiveAttenuatorFaceplate-B_Paste.gbr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]
2026-09-24 Add docs, drawings, BOM and PDF build for the Passive Attenuator
    Adds the README, user manual, assembly guide, BOM (Markdown and CSV)
    and CC BY-NC-SA 4.0 license, so buyers and builders can use the module
    without asking. Panel, assembly and patch drawings are generated from
    the KiCad files by stdlib-only scripts in docs/drawings, and the PDFs
    are built by the shared schenktronics-docs-tools Action.
    Renames the faceplate gerber zip, which had the same name as the main
    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
    [BOM.csv]
2026-09-24 Describe the faceplate as an aluminium PCB
    The docs assumed FR4, but the faceplates are made as aluminium PCBs.
    The design only uses the front copper layer, so FR4 still works.
    [BOM.csv]
2026-10-01 Update to kicad 10 Change logo on faceplate Change faceplate jack graphics to round from square Regenerate gerbers
    [PassiveAttenuatorFaceplate-B_Cu.gbr, PassiveAttenuatorFaceplate-B_Mask.gbr, PassiveAttenuatorFaceplate-B_Paste.gbr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]
2026-10-01 Regenerate the panel drawing for the new faceplate
    The faceplate moved to KiCad 10's S-expression format, the jack
    indicator graphics changed from square outlines to round rings, and
    the logo became a footprint. The old regex-based parser couldn't read
    the new file, so make_panel_svg.py now uses a small generic
    S-expression reader and resolves the logo's polygons through its
    footprint's position and rotation. Verified against a kicad-cli render
    of the faceplate's silkscreen.
    Updated the manual's wording from "outlined/solid box" to "thin/bold
    ring" to match the new jack graphics.
2026-10-07 Faceplate: S-mark + new ST-02 on the hole-centered scheme, Orbitron text
    S-mark moves from lower-left to the gap right of the bottom hole
    (1.09mm margin each side) -- too narrow for the full wordmark, so this
    is the small-mark branch of the placement rule. Adds ST-02, which didn't
    exist before, vertical, justify-left anchored to the S-mark's bottom in
    the left gap. Header ("Atten.") switched from italic KiCad stroke font
    to upright Orbitron.
    [PassiveAttenuatorFaceplate.kicad_pcb]
2026-10-07 Faceplate: rename header "Atten." to "Attenuate", narrow to fit 15mm width
    Width dropped from 2.5mm to 2mm (height unchanged at 2.5mm) to get the
    longer name under the 3 HP panel's width. Also carries KiCad's own
    render_cache entries for the Orbitron text, written on save -- confirms
    the font is rendering correctly, not falling back.
    [PassiveAttenuatorFaceplate.kicad_pcb]
2026-10-07 Faceplate: pot tick marks, jack ring cleanup; regen docs
    - Add the Attenuverter's knob tick-mark fan (21 lines, same pattern and
    orientation) around both pots, at the two plain-hole locations that
    had no decorative ring.
    - Remove the input jack's ring entirely; output jack ring corrected to
    an exact circle (was off-center by 0.5mm on one of the two) and later
    resized to 11mm by hand in KiCad.
    - Regenerate docs/images/panel.svg and panel-plain.svg from the updated
    faceplate via make_panel_svg.py, and fix two hardcoded "thin ring"
    captions in that script and in manual.md that no longer matched the
    new no-ring/bold-ring convention. Manual no longer hardcodes a ring
    diameter, so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
    [PassiveAttenuatorFaceplate.kicad_pcb]
2026-10-07 Title blocks: add logo worksheet link and fill in consistent fields
    Set page_layout_descr_file (pcbnew and schematic) to the real
    Schenktronics worksheet path. Neither PCB had a title block; added one
    each, rev 1.0 to match the real "v1.0" silkscreen text, company
    "Schenktronics".
    [PassiveAttenuator.kicad_pcb, PassiveAttenuatorFaceplate.kicad_pcb]
2026-10-07 Title block: add Dolibarr PCB ref (PCB-ST02-MAIN / PCB-ST02-FACE) as comment 4
    [PassiveAttenuator.kicad_pcb, PassiveAttenuatorFaceplate.kicad_pcb]
2026-10-07 Main PCB: add logo + harmonized branding text
    This board had no logo at all. Added the medium S-mark plus
    "schenktronics.com" and "ST-02 v1.0\nPassive Attenuator" in the clear
    gap between the second jack and second pot -- the only real opening
    given the pot footprints eat into the middle of the board.
    Tried the CC BY-NC-SA roundels + text too, matching the Multiple, but
    verified via kicad-cli renders that there isn't enough clear vertical
    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
    [PassiveAttenuator.kicad_pcb]
2026-10-07 Main PCB: hand-tuned branding placement, add CC license text
    Nathan's own edit in KiCad: refined the logo/text placement and added
    "CC BY-NC-SA 4.0" text (matching the other boards -- text only, no icon
    roundels). File also came back saved in modern KiCad format, which
    accounts for most of this diff's size.
    [PassiveAttenuator.kicad_pcb]
2026-10-08 Regenerate gerbers: logo, branding text, and fixed-ring output
    Main board now has the S-mark logo and ST-02 branding text that didn't
    exist in the last gerber set at all. Faceplate picks up the squeezed
    wordmark, tick marks, and the resized/removed jack rings.
    Cleaned up stale duplicate output from an older KiCad version's naming
    (*_SilkS.gbr vs this version's *_Silkscreen.gbr; old .plt/.gbr drill
    maps superseded by the PDF ones; a leftover drill report regenerated
    fresh). Both zips rebuilt to match.
    [PassiveAttenuator-B_Cu.gbr, PassiveAttenuator-B_Mask.gbr, PassiveAttenuator-B_Paste.gbr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]
2026-10-08 Rename product to Levels
    Faceplate silkscreen header changed from "Attenuate" to "Levels"
    (ST-02 part number unchanged). Updates docs, README and the generated
    panel drawings to match; renames the PDF outputs to levels-*.pdf.
    The main PCB's back silkscreen still reads "Passive Attenuator", so
    the assembly guide's description of it is left as-is.
    [BOM.csv, PassiveAttenuatorFaceplate.kicad_pcb]
2026-10-08 Update title blocks and docs for the main PCB's silkscreen change
    Nathan changed the main PCB's back silkscreen from "Passive Attenuator"
    to "Levels" (ST-02 unchanged). Updates both boards' KiCad title_block
    fields (still said "Passive Attenuator"/"Passive Attenuator Faceplate"),
    the BOM's main-PCB label, and the assembly guide's description of what's
    printed on the back.
    [BOM.csv, PassiveAttenuator.kicad_pcb, PassiveAttenuatorFaceplate.kicad_pcb]
2026-10-08 Restructure into hardware/ and manufacturing/, matching Quad Mixer's layout
    PassiveAttenuator/ -> hardware/levels/ (source) and manufacturing/levels/
    (gerbers, moved out). PassiveAttenuatorFaceplate/ -> hardware/panel/ and
    manufacturing/panel/ (gerbers plus the panel .dxf/.bak drawing). KiCad
    project filenames are unchanged, only their containing folder moved.
    Also deletes a stray fp-846B.tmp (a leftover KiCad temp/lock file) and
    two stray .DS_Store files found along the way.
    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
    [BOM.ods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]
2026-10-08 Rename the KiCad projects from PassiveAttenuator to Levels
    PassiveAttenuator -> Levels (main PCB), PassiveAttenuatorFaceplate ->
    LevelsFaceplate, matching the product's current name and the
    hardware/levels + hardware/panel folders. Renames every project file
    and fixes the internal self-references inside .kicad_pro (filename/
    netlist/sheet name fields) and the legacy .pro's LastNetListRead line.
    Also fixes sym-lib-table (untracked, but used when the project is
    actually opened), which pointed at an absolute path from before the
    last two restructures (~/Products/Attenuator/PassiveAttenuator/...) --
    switched to ${KIPRJMOD}-relative, matching Quad Mixer's convention.
    Regenerated the gerbers and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
    [Levels-B_Cu.gbr, Levels-B_Mask.gbr, Levels-B_Paste.gbr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]
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2026-10-09 Center jacks on PCB
    [Levels.kicad_pcb, Levels.step]
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2026-10-09 Add assembly 3d model
    [ST-02_Levels.step]
2026-10-09 Switch to a bushingless pot and non-skirted knob
    New BOM: Bourns PTV09A-4020F-B104 (bushingless, no center detent) and
    Davies 1221-J, replacing the old TT Electronics panel-mount pot and
    skirted 1227-J knob. Same mounting style as the Attenuverter's pot,
    held by its two PCB lugs with no nut to cover, so the assembly guide's
    faceplate and knob steps drop the pot-nut handling accordingly.
    Also ports the assembly-guide drawing generator to the KiCad 10
    S-expression format the main PCB file is actually in (it was still
    regex-based for KiCad 5/6 and silently failed to parse anything), and
    fixes it drawing the Schenktronics logo footprint as if it were a part.
    [BOM.csv]
2026-10-09 Replace product photos with STEP-based outline drawings
    Same treatment as the Passive Multiple: outline-front.svg,
    outline-side.svg, outline-iso-top-left.svg and outline-bare-parts.svg
    are real HLR projections generated from the newly added assembly,
    panel and board STEP files, not diagrams or photos. They replace
    front.jpg and pcb-and-panel.jpg in the README, manual and assembly
    guide; the four isometric corners are all generated every run so
    there's a fresh set to pick a hero angle from.
    The shared generator (schenktronics-business) needed a fix to handle
    this board: outline-bare-parts.svg crashed because a pot body
    overhangs the bare board's edge by 0.5mm, past its matching tolerance.
2026-10-09 Stop tracking generated manufacturing files
    [Levels-B_Cu.gbr, Levels-B_Mask.gbr, Levels-B_Paste.gbr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]
